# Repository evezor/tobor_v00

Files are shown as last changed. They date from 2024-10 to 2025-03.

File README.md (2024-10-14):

# tobor_v00
Tobor (robot spelled backwards), was built to be the most versatile open-source robotics system

Find out more about this project, additional source files will be released [here](https://www.crowdsupply.com/evezor-inc/tobor-robotics-and-automation-platform)

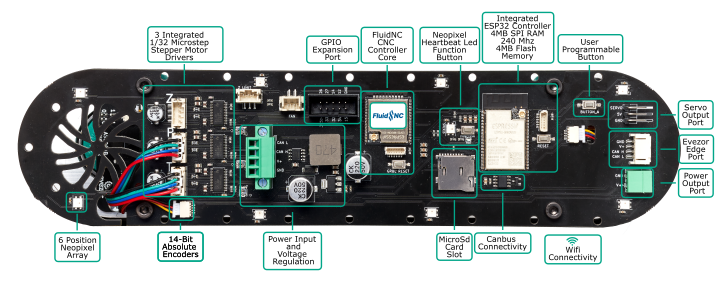
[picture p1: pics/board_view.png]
board_view

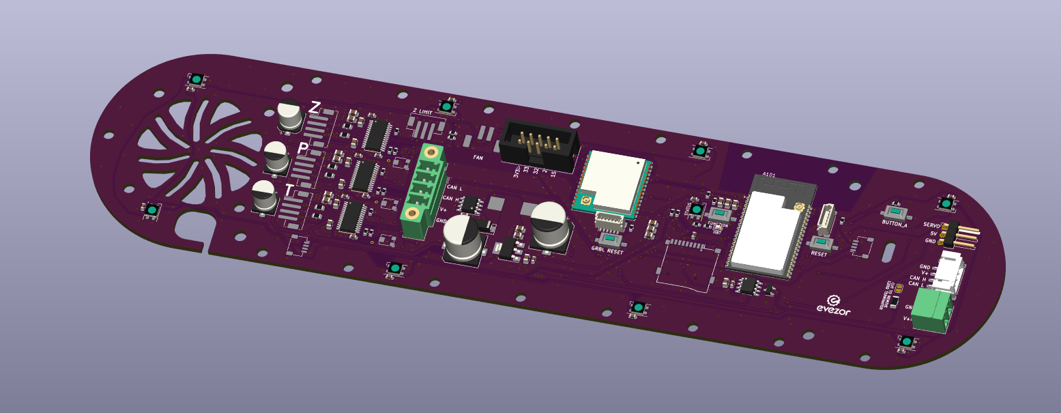
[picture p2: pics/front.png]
front_view

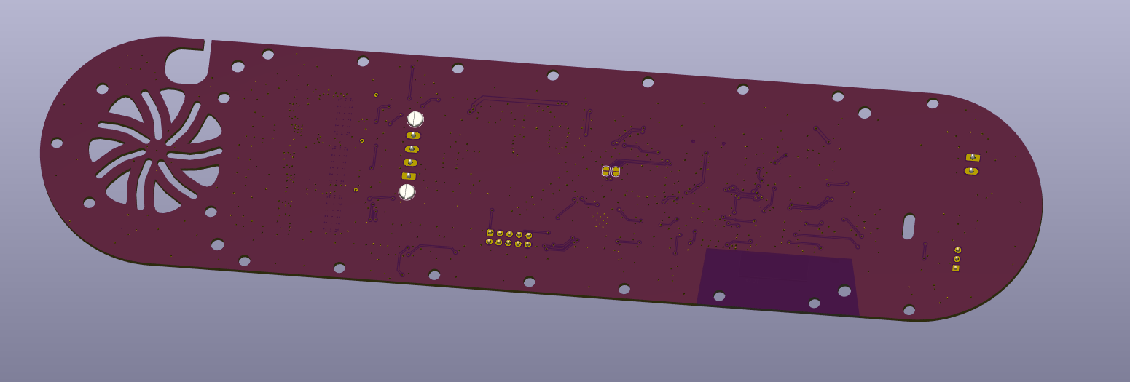
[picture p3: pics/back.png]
back

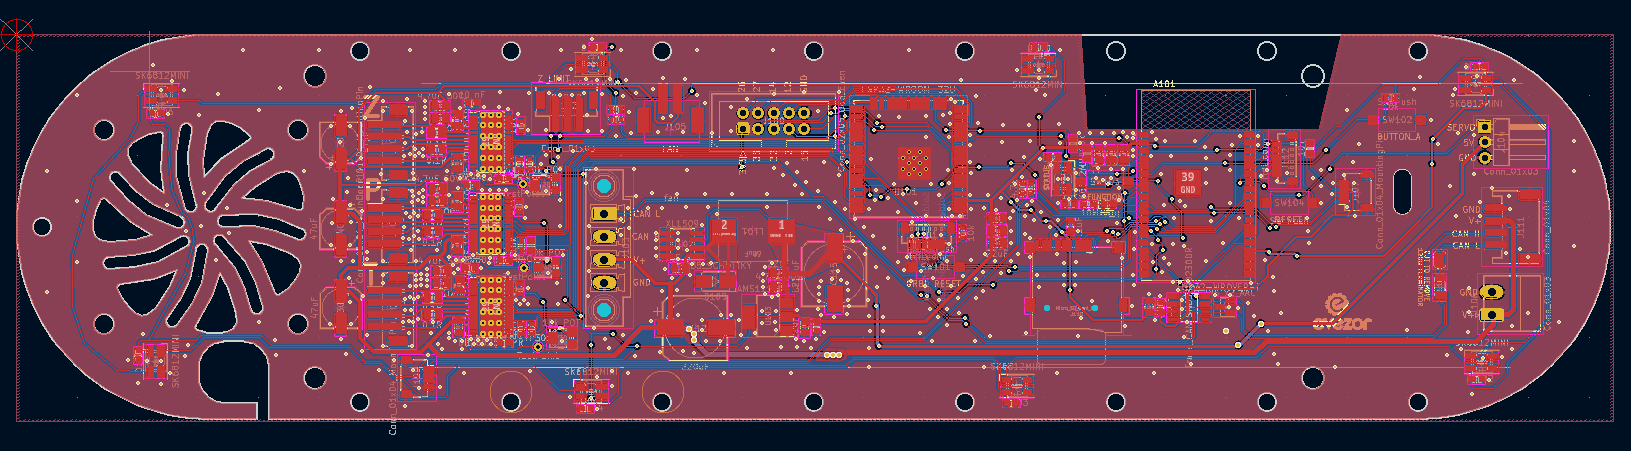
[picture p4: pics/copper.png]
copper


Tobor Robot Arm Features

* ESP32 microcontroller with 4 MB SPIRAM
    * Runs Micropython
* 3 DRV8825 stepper motor drivers
* 2 AS5048B 14-bit absolute encoders
    * Allows for low/no motion homing
    * Collaborative programming
* 8 position addressable LED ring
    * Can be used to display states of motors or the machine
* External stepper driver and peripheral port
* CNC controller powered by Fluid NC with dedicated FTDI and reset switch
* Micro-SD card slot
* WiFi enabled
* CANbus Edge Board Interface
* Servo header
* 24 VDC power input
* 1 user programmable tactile button
* Reset button
* FTDI port
* Edgeboard standards
    * Heartbeat LED
    * Function button
    * Status addressable LED

Find out more about this project, additional source files will be released [here](https://www.crowdsupply.com/evezor-inc/tobor-robotics-and-automation-platform)

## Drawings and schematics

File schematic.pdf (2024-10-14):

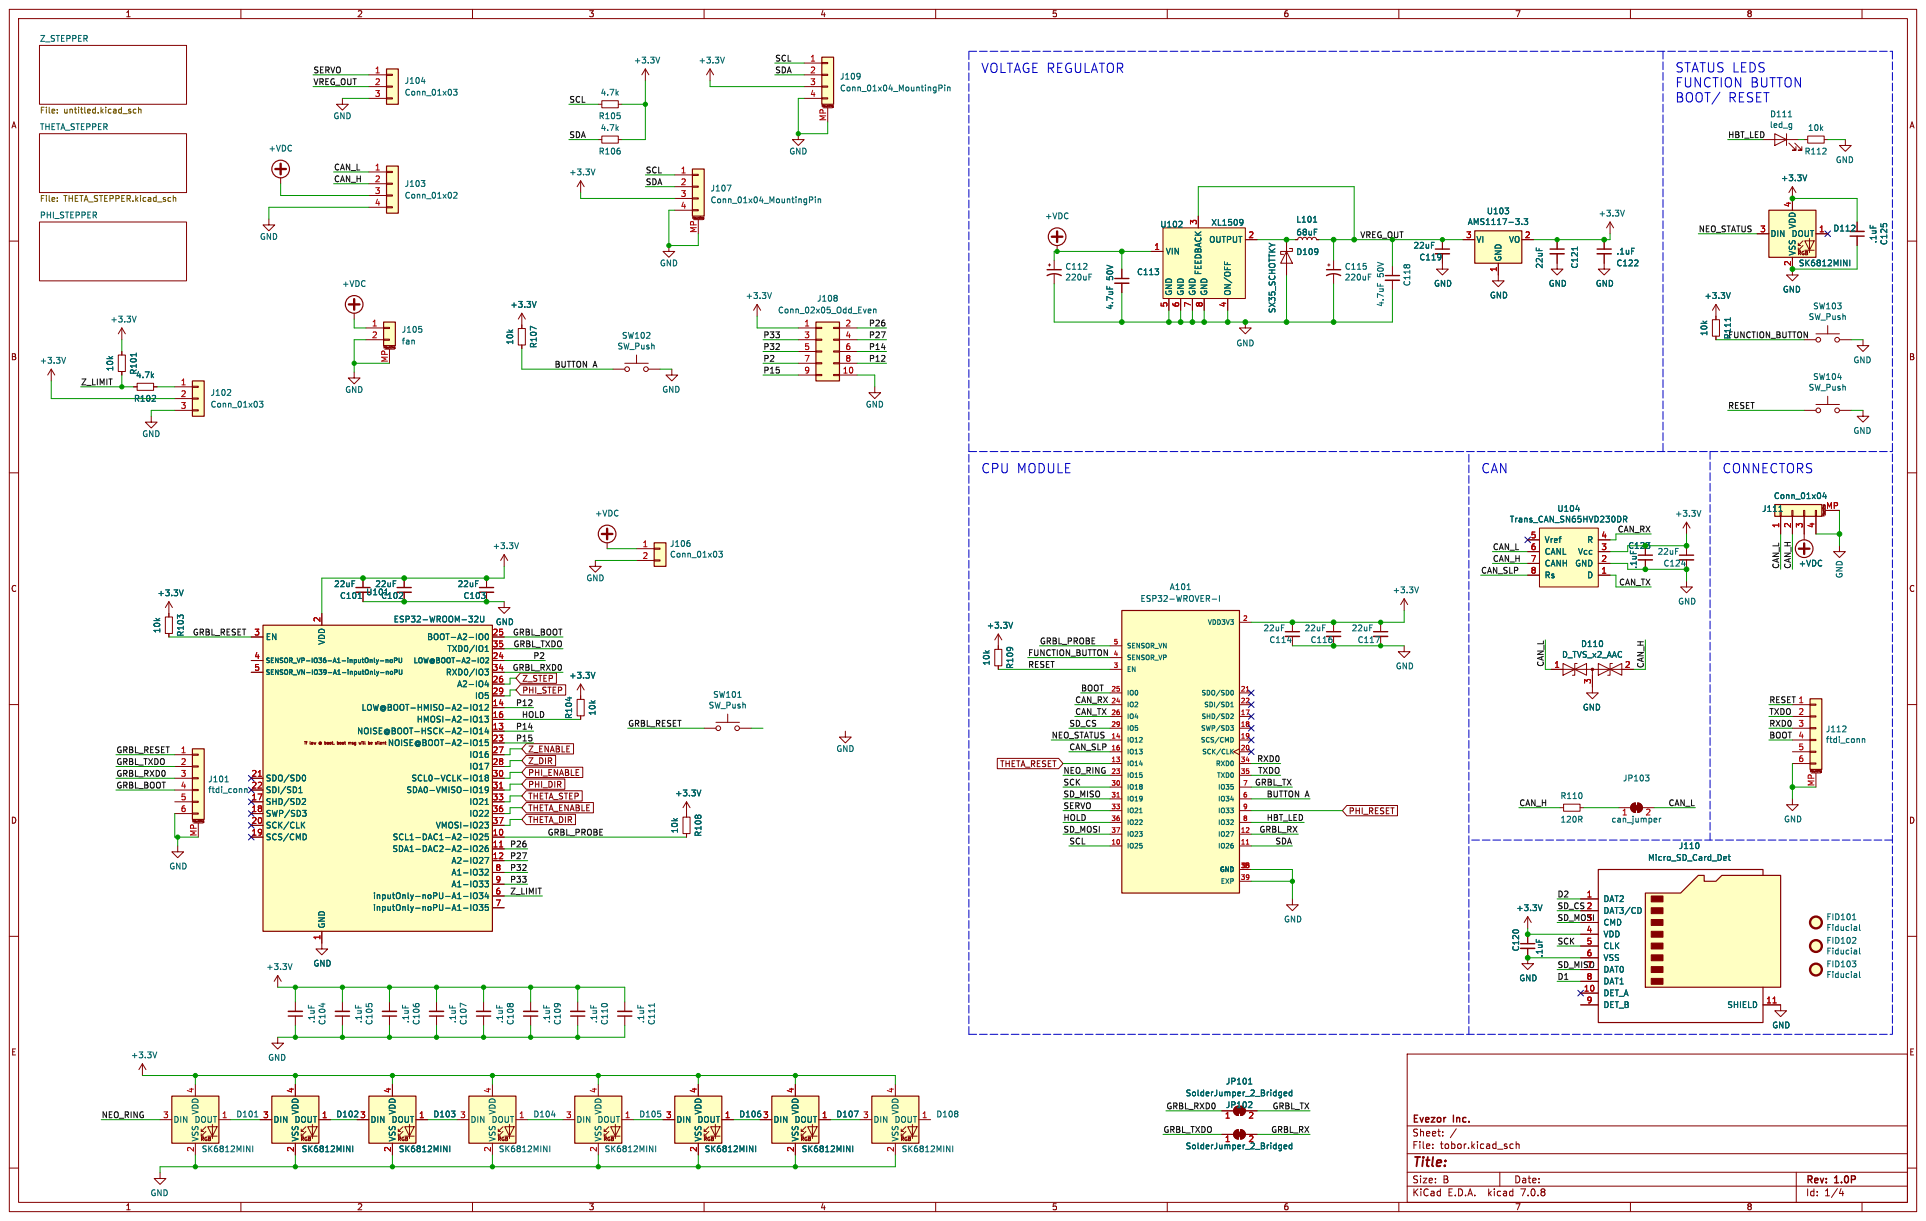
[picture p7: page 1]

2 SCK/CLK 20 SDO/SD0 21 SDI/SD1 22 NOISE@BOOT-A2-IO15 23

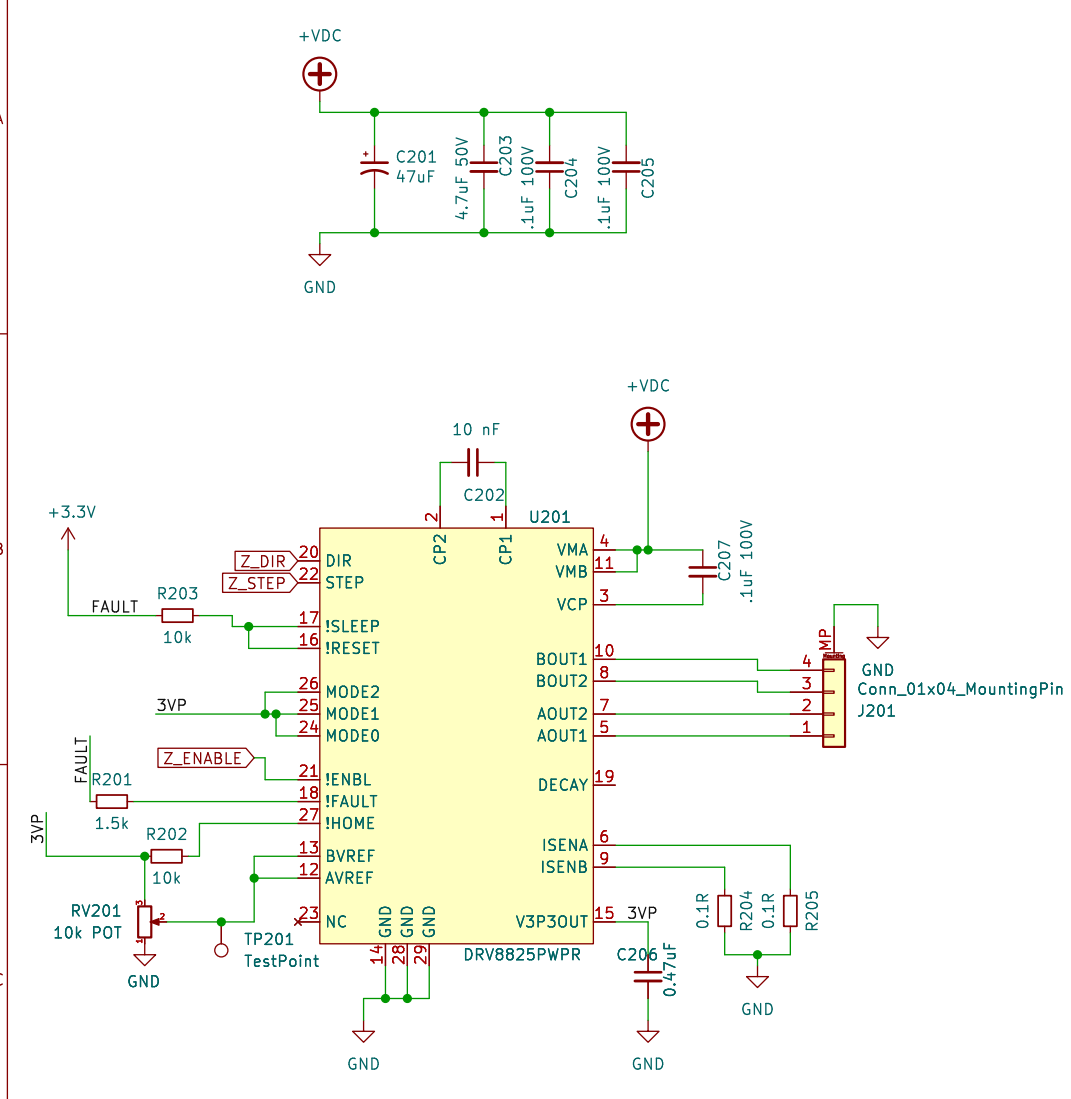
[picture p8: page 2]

1 BOUT1 10 VMB 11 AVREF 12 BVREF 13 GND 14 V3P3OUT 15

Id: 2/4 Title: File: untitled.kicad_sch Sheet: /Z_STEPPER/

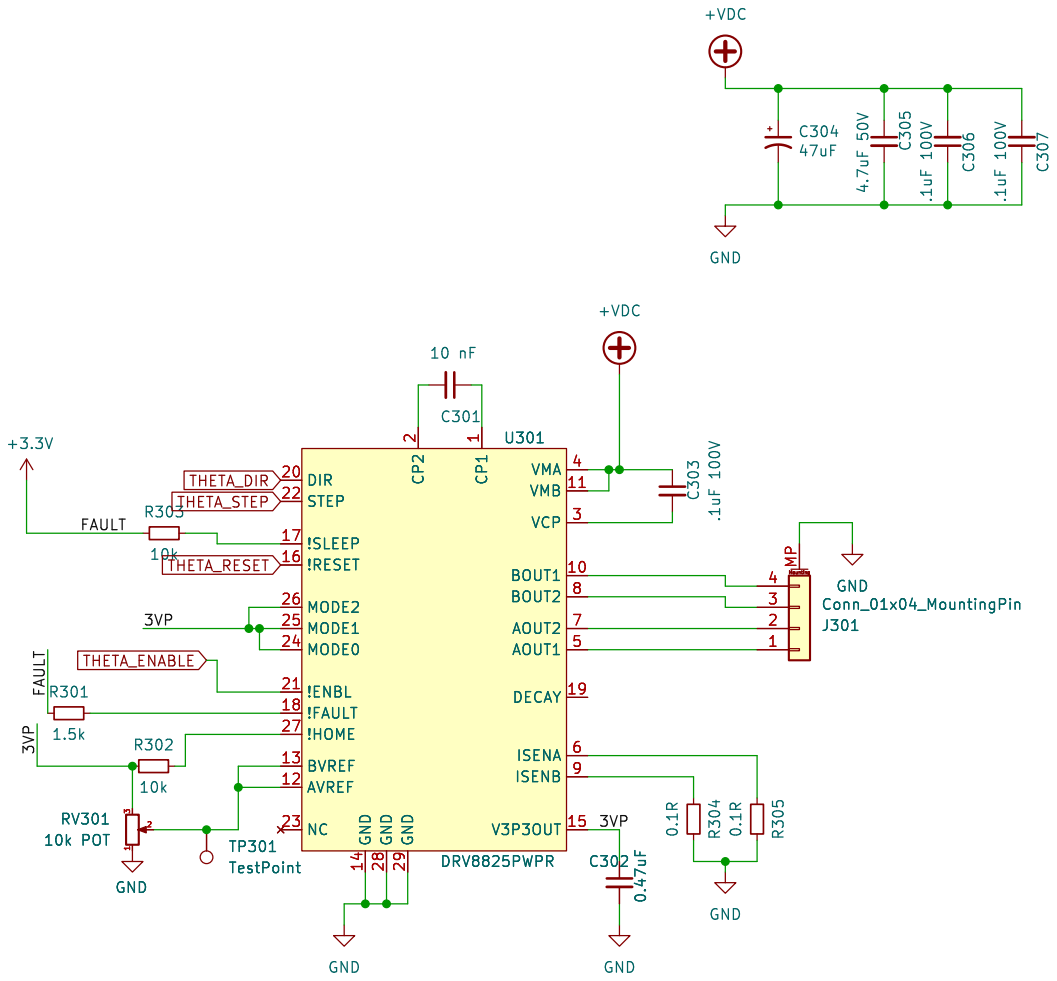
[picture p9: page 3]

Id: 3/4 Title: File: THETA_STEPPER.kicad_sch Sheet: /THETA_STEPPER/ C303 .1uF 100V+3.3V R301

1 BOUT1 10 VMB 11 AVREF 12 BVREF 13 GND 14 V3P3OUT 15

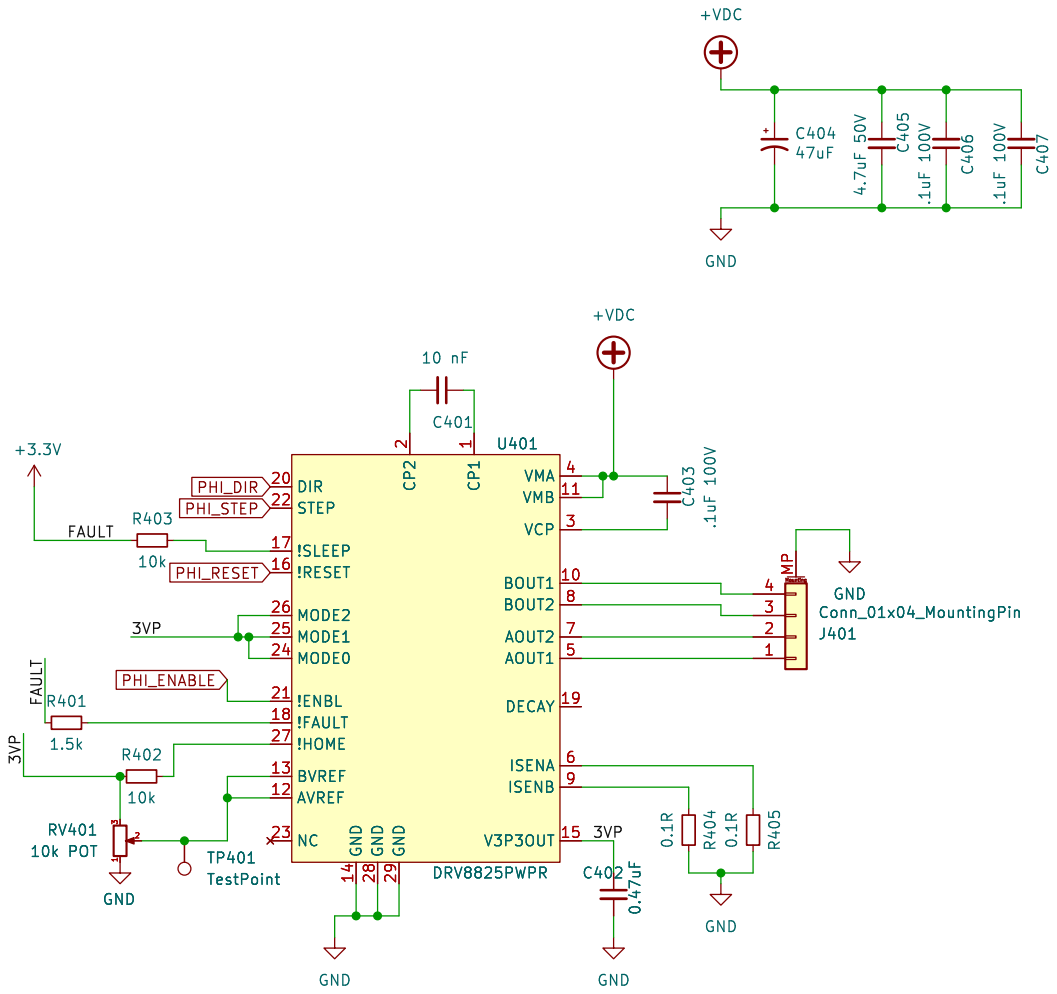
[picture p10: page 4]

4 MP C402 0.47uF U401 DRV8825PWPR CP1
Id: 4/4 Title: File: PHI_STEPPER.kicad_sch Sheet: /PHI_STEPPER/ CP1

1 BOUT1 10 VMB 11 AVREF 12 BVREF 13 GND 14 V3P3OUT 15

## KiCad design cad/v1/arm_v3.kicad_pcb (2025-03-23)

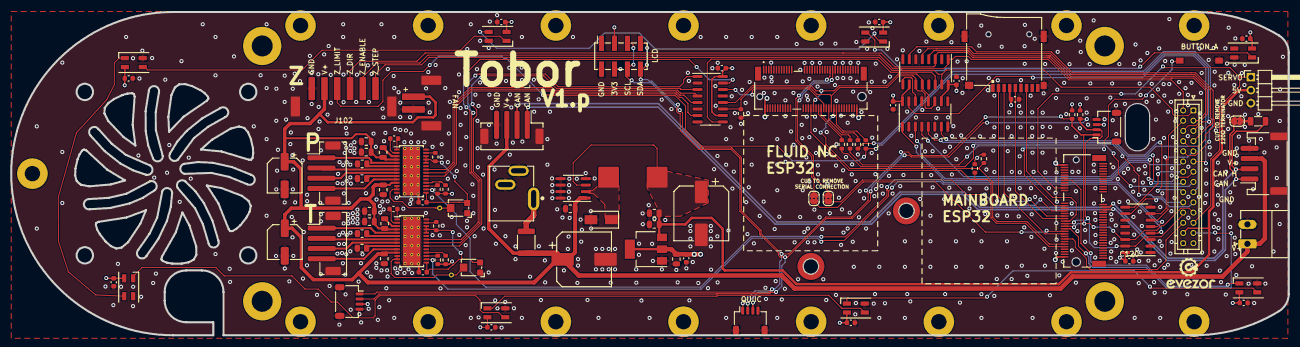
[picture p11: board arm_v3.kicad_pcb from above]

Board: 4 copper layers, 250.2 x 63.3 mm, 121 parts (0 on the bottom side), 98 nets.

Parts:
C101, C102, C103, C104, C105, C106, C107, C108, C114, C116, C117, C118, C119, C120: .1uF; C_0603_1608Metric
C109, C111: 220uF; CP_Elec_10x10.5
C110, C112, C205, C305: 4.7uF 50V; C_0805_2012Metric
C113, C115: 22uF; C_0805_2012Metric
C201, C301: 10 nF; C_0603_1608Metric
C202, C302: 0.47uF; C_0603_1608Metric
C203, C206, C207, C303, C306, C307: .1uF 100V; C_0805_2012Metric
C204, C304: 47uF; CP_Elec_6.3x7.7
D101, D102, D103, D104, D105, D106, D107, D108: SK6812MINI; LED_SK6812MINI_PLCC4_3.5x3.5mm_P1.75mm
D109: SX35_SCHOTTKY; D_SMA
F101: Polyfuse_Small; Fuse_1812_4532Metric
H101, H102, H103, H104: MountingHole; MountingHole_4.1mm_M4_DIN965_Pad
H105, H106, H107, H108, H109, H110, H111, H112, H113, H114, H115, H116, H117, H118, H119, H120, H121: MountingHole; MountingHole_3mm_Pad
H122, H123: MountingHole; Mounting_Wuerth_WA-SMSI-M2_H2.5mm_9774025243
J101: Conn_01x03; PhoenixContact_MC_1,5_2-G-3.81_1x02_P3.81mm_Horizontal
J102: Conn_01x06_MountingPin; CONN_JST_XH_6_VERTICAL
J103: fan; JST_XH_2_VERTICAL
J104: Conn_01x03; PinHeader_1x03_P2.54mm_Horizontal
J105: Conn_02x04_Odd_Even; PinSocket_2x04_P2.54mm_Vertical_SMD
J106, J108, J110: Conn_01x04_MountingPin; JST_SH_SM04B-SRSS-TB_1x04-1MP_P1.00mm_Horizontal
J107: Barrel_Jack_Switch; Vertical_barrel
J109: Conn_02x10_Odd_Even; JST_PHD_B28B-PHDSS_2x14_P2.00mm_Vertical
J111: Micro_SD_Card_Det; Conn_uSDcard
J112: Conn_01x04; JST_PH_S4B-PH-SM4-TB_1x04-1MP_P2.00mm_Horizontal
J113: Conn_01x02; JST_PH_B4B-PH-SM4-TB_1x04-1MP_P2.00mm_Vertical
J114, J115: Bus_M.2_Socket_E_ESP32; AMPHENOL_MDT420E02002
J201, J301: Conn_01x04_MountingPin; JST_PH_B4B-PH-SM4-TB_1x04-1MP_P2.00mm_Vertical
JP101, JP102: SolderJumper_2_Bridged; SolderJumper-2_P1.3mm_Bridged2Bar_RoundedPad1.0x1.5mm
JP103: can_jumper; SolderJumper-2_P1.3mm_Bridged2Bar_RoundedPad1.0x1.5mm
L101: 68uF; INDUCTOR-68uH
R101, R102: 4.7k; R_0603_1608Metric
R103: 120R; R_1206_3216Metric
R104, R105, R106, R202, R203, R302, R303: 10k; R_0603_1608Metric
R107, R108, R109, R110: 220R; R_0603_1608Metric
R201, R301: 1.5k; R_0603_1608Metric
R204, R205, R304, R305: 0.1R; R_0805_2012Metric
RV201, RV301: 10k POT; Potentiometer_Bourns_TC33X_Vertical
SW101: SW_Push; SWITCH_2x3_SMD_TACTILE_GREEN
TP201, TP301: TestPoint; TestPoint_THTPad_D1.0mm_Drill0.5mm
U101: XL1509; SOIC-8_3.9x4.9mm_P1.27mm
U102: AMS1117-3.3; SOT-223-3_TabPin2
U103, U104, U105: 74AHCT595; SOIC-16_3.9x9.9mm_P1.27mm
U106: PCF8574; SOIC-16_3.9x9.9mm_P1.27mm
U201, U301: DRV8825PWPR; HTSSOP-28-1EP_4.4x9.7mm_P0.65mm_EP3.4x9.5mm_ThermalVias

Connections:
+3V3: C101.2, C102.2, C103.2, C104.2, C105.2, C106.2, C107.2, C108.2, C114.1, C115.1, C116.1, C117.2, C118.2, C119.2, C120.1, D101.4 (VDD), D102.4 (VDD), D103.4 (VDD), D104.4 (VDD), D105.4 (VDD), D106.4 (VDD), D107.4 (VDD), D108.4 (VDD), J105.3, J105.4, J106.3, J108.3, J109.27, J110.3, J111.4 (VDD), J114.2 (3.3V), J114.74 (3.3V), J115.2 (3.3V), J115.74 (3.3V), R101.1, R102.1, R104.2, R106.2, R201.2, R203.2, R301.2, R303.2, U102.2 (VO), U103.10 (~SRCLR), U103.16 (VCC), U104.10 (~SRCLR), U104.16 (VCC), U105.10 (~SRCLR), U105.16 (VCC), U106.16 (VDD)
+5V: C111.1, C112.1, C113.1, J104.2, J109.26, L101.1, U101.3 (FEEDBACK), U102.3 (VI)
+VDC: C109.1, C110.1, C203.1, C204.1, C205.1, C206.2, C207.2, C303.1, C304.1, C305.1, C306.2, C307.2, F101.1, J101.1, J102.5, J103.1, J112.3, J113.3, U101.1 (VIN), U201.4 (VMA), U201.11 (VMB), U301.4 (VMA), U301.11 (VMB)
/A_DIR: J109.8, U104.7 (QH)
/A_ENABLE: J109.7, U104.5 (QF)
/A_LIMIT: J109.10, R108.1
/A_RESET: J109.9, U106.7 (P3)
/A_STEP: J109.6, U104.4 (QE)
/BUTTON A: J114.34, SW101.1
/B_DIR: J109.13, U105.3 (QD)
/B_ENABLE: J109.12, U105.1 (QB)
/B_LIMIT: J109.15, R109.1
/B_RESET: J109.14, U106.9 (P4)
/B_STEP: J109.11, U105.15 (QA)
/CAN_H: J112.2, J113.2, J114.35 (CAN_H), R103.2
/CAN_L: J112.1, J113.1, J114.37 (CAN_L), JP103.2 (B)
/C_DIR: J109.18, U105.7 (QH)
/C_ENABLE: J109.17, U105.5 (QF)
/C_LIMIT: J109.20, R110.1
/C_RESET: J109.19, U106.10 (P5)
/C_STEP: J109.16, U105.4 (QE)
/GRBL_PROBE: J114.66, J115.38, R104.1
/GRBL_RX: J114.38, JP102.2 (B)
/GRBL_RXD0: J115.53 (UART_RX), JP101.1 (A)
/GRBL_TX: J114.54, JP101.2 (B)
/GRBL_TXDO: J115.55 (UART_TX), JP102.1 (A)
/HOLD: J114.64, J115.56, R106.1
/I2S_CLK: J115.54, R105.2, U103.11 (SRCLK), U104.11 (SRCLK), U105.11 (SRCLK)
/I2S_DATA: J115.48, U103.14 (SER)
/I2S_WS: J115.40, U103.12 (RCLK), U104.12 (RCLK), U105.12 (RCLK)
/NEO_RING: D101.3 (DIN), J114.14
/P25: J109.25, J114.52
/P60: J109.24, J114.60
/PHI_STEPPER/3VP: C302.1, R302.2, RV301.3, U301.15 (V3P3OUT), U301.24 (MODE0), U301.25 (MODE1), U301.26 (MODE2)
/SCK: J111.5 (CLK), J114.44
/SCL: J105.5, J105.6, J106.1, J108.1, J109.21, J110.1, J114.50, R101.2, U106.14 (SCL)
/SDA: J105.7, J105.8, J106.2, J108.2, J109.22, J110.2, J114.48, R102.2, U106.15 (SDA)
/SD_CS: J111.2 (DAT3/CD), J114.42
/SD_MISO: J111.7 (DAT0), J114.46
/SD_MOSI: J111.3 (CMD), J114.56
/SERVO: J104.1, J109.23, J114.20
/THETA_STEPPER/3VP: C202.1, R202.2, RV201.3, U201.15 (V3P3OUT), U201.24 (MODE0), U201.25 (MODE1), U201.26 (MODE2)
/Z_DIR: J102.3, J109.3, U104.3 (QD)
/Z_ENABLE: J102.2, J109.2, U104.1 (QB)
/Z_LIMIT: J102.4, J109.5, R107.1
/Z_RESET: J109.4, U106.6 (P2)
/Z_STEP: J102.1, J109.1, U104.15 (QA)
GND: C101.1, C102.1, C103.1, C104.1, C105.1, C106.1, C107.1, C108.1, C109.2, C110.2, C111.2, C112.2, C113.2, C114.2, C115.2, C116.2, C117.1, C118.1, C119.1, C120.2, C202.2, C204.2, C205.2, C206.1, C207.1, C302.2, C304.2, C305.2, C306.1, C307.1, D101.2 (VSS), D102.2 (VSS), D103.2 (VSS), D105.2 (VSS), D106.2 (VSS), D107.2 (VSS), D108.2 (VSS), D109.2 (A), J101.2, J102.6, J102.MP (MountPin), J103.2, J103.MP (MountPin), J104.3, J105.1, J105.2, J106.4, J106.MP (MountPin), J107.2, J107.3, J108.4, J108.MP (MountPin), J109.28, J110.4, J110.MP (MountPin), J111.6 (VSS), J111.11 (SHIELD), J112.4, J112.MP (MountPin), J113.4, J113.MP (MountPin), J114.1 (GND), J114.7 (GND), J114.18 (GND), J114.33 (GND), J114.36 (GND), J114.39 (GND), J114.45 (GND), J114.57 (GND), J114.63 (GND), J114.69 (GND), J114.75 (GND), J115.1 (GND), J115.7 (GND), J115.18 (GND), J115.33 (GND), J115.36 (GND), J115.39 (GND), J115.45 (GND), J115.57 (GND), J115.63 (GND), J115.69 (GND), J115.75 (GND), J201.MP (MountPin), J301.MP (MountPin), R105.1, R204.1, R205.1, R304.1, R305.1, RV201.1, RV301.1, SW101.2, U101.4 (ON/OFF), U101.5 (GND), U101.6 (GND), U101.7 (GND), U101.8 (GND), U102.1 (GND), U103.8 (GND), U103.13 (~OE), U104.8 (GND), U104.13 (~OE), U105.8 (GND), U105.13 (~OE), U106.1 (A0), U106.2 (A1), U106.3 (A2), U106.8 (VSS), U201.14 (GND), U201.28 (GND), U201.29 (GND), U301.14 (GND), U301.28 (GND), U301.29 (GND)
unnamed: D101.1 (DOUT), D102.3 (DIN)
unnamed: D102.1 (DOUT), D103.3 (DIN)
unnamed: D103.1 (DOUT), D104.3 (DIN)
unnamed: D104.1 (DOUT), D105.3 (DIN)
unnamed: D105.1 (DOUT), D106.3 (DIN)
unnamed: D106.1 (DOUT), D107.3 (DIN)
unnamed: D107.1 (DOUT), D108.3 (DIN)
unnamed: D109.1 (K), L101.2, U101.2 (OUTPUT)
unnamed: F101.2, J107.1
unnamed: J115.44, R110.2
unnamed: J115.46, R109.2
unnamed: J115.52, R108.2
unnamed: J115.58, R107.2
unnamed: J201.1, U201.5 (AOUT1)
unnamed: J201.2, U201.7 (AOUT2)
unnamed: J201.3, U201.8 (BOUT2)
unnamed: J201.4, U201.10 (BOUT1)
unnamed: J301.1, U301.5 (AOUT1)
unnamed: J301.2, U301.7 (AOUT2)
unnamed: J301.3, U301.8 (BOUT2)
unnamed: J301.4, U301.10 (BOUT1)
unnamed: JP103.1 (A), R103.1
unnamed: U103.9 (QH'), U104.14 (SER)
unnamed: U104.9 (QH'), U105.14 (SER)
unnamed: R201.1, U201.18 (!FAULT)
unnamed: R202.1, U201.27 (!HOME)
unnamed: R203.1, U201.17 (!SLEEP)
unnamed: RV201.2, TP201.1, U201.12 (AVREF), U201.13 (BVREF)
unnamed: C201.1, U201.1 (CP1)
unnamed: C201.2, U201.2 (CP2)
unnamed: R205.2, U201.6 (ISENA)
unnamed: R204.2, U201.9 (ISENB)
unnamed: C203.2, U201.3 (VCP)
unnamed: R301.1, U301.18 (!FAULT)
unnamed: R302.1, U301.27 (!HOME)
unnamed: R303.1, U301.17 (!SLEEP)
unnamed: RV301.2, TP301.1, U301.12 (AVREF), U301.13 (BVREF)
unnamed: C301.1, U301.1 (CP1)
unnamed: C301.2, U301.2 (CP2)
unnamed: R305.2, U301.6 (ISENA)
unnamed: R304.2, U301.9 (ISENB)
unnamed: C303.2, U301.3 (VCP)
PHI_DIR: U103.7 (QH), U301.20 (DIR)
PHI_ENABLE: U103.5 (QF), U301.21 (!ENBL)
PHI_RESET: U106.5 (P1), U301.16 (!RESET)
PHI_STEP: U103.4 (QE), U301.22 (STEP)
THETA_DIR: U103.3 (QD), U201.20 (DIR)
THETA_ENABLE: U103.1 (QB), U201.21 (!ENBL)
THETA_RESET: U106.4 (P0), U201.16 (!RESET)
THETA_STEP: U103.15 (QA), U201.22 (STEP)

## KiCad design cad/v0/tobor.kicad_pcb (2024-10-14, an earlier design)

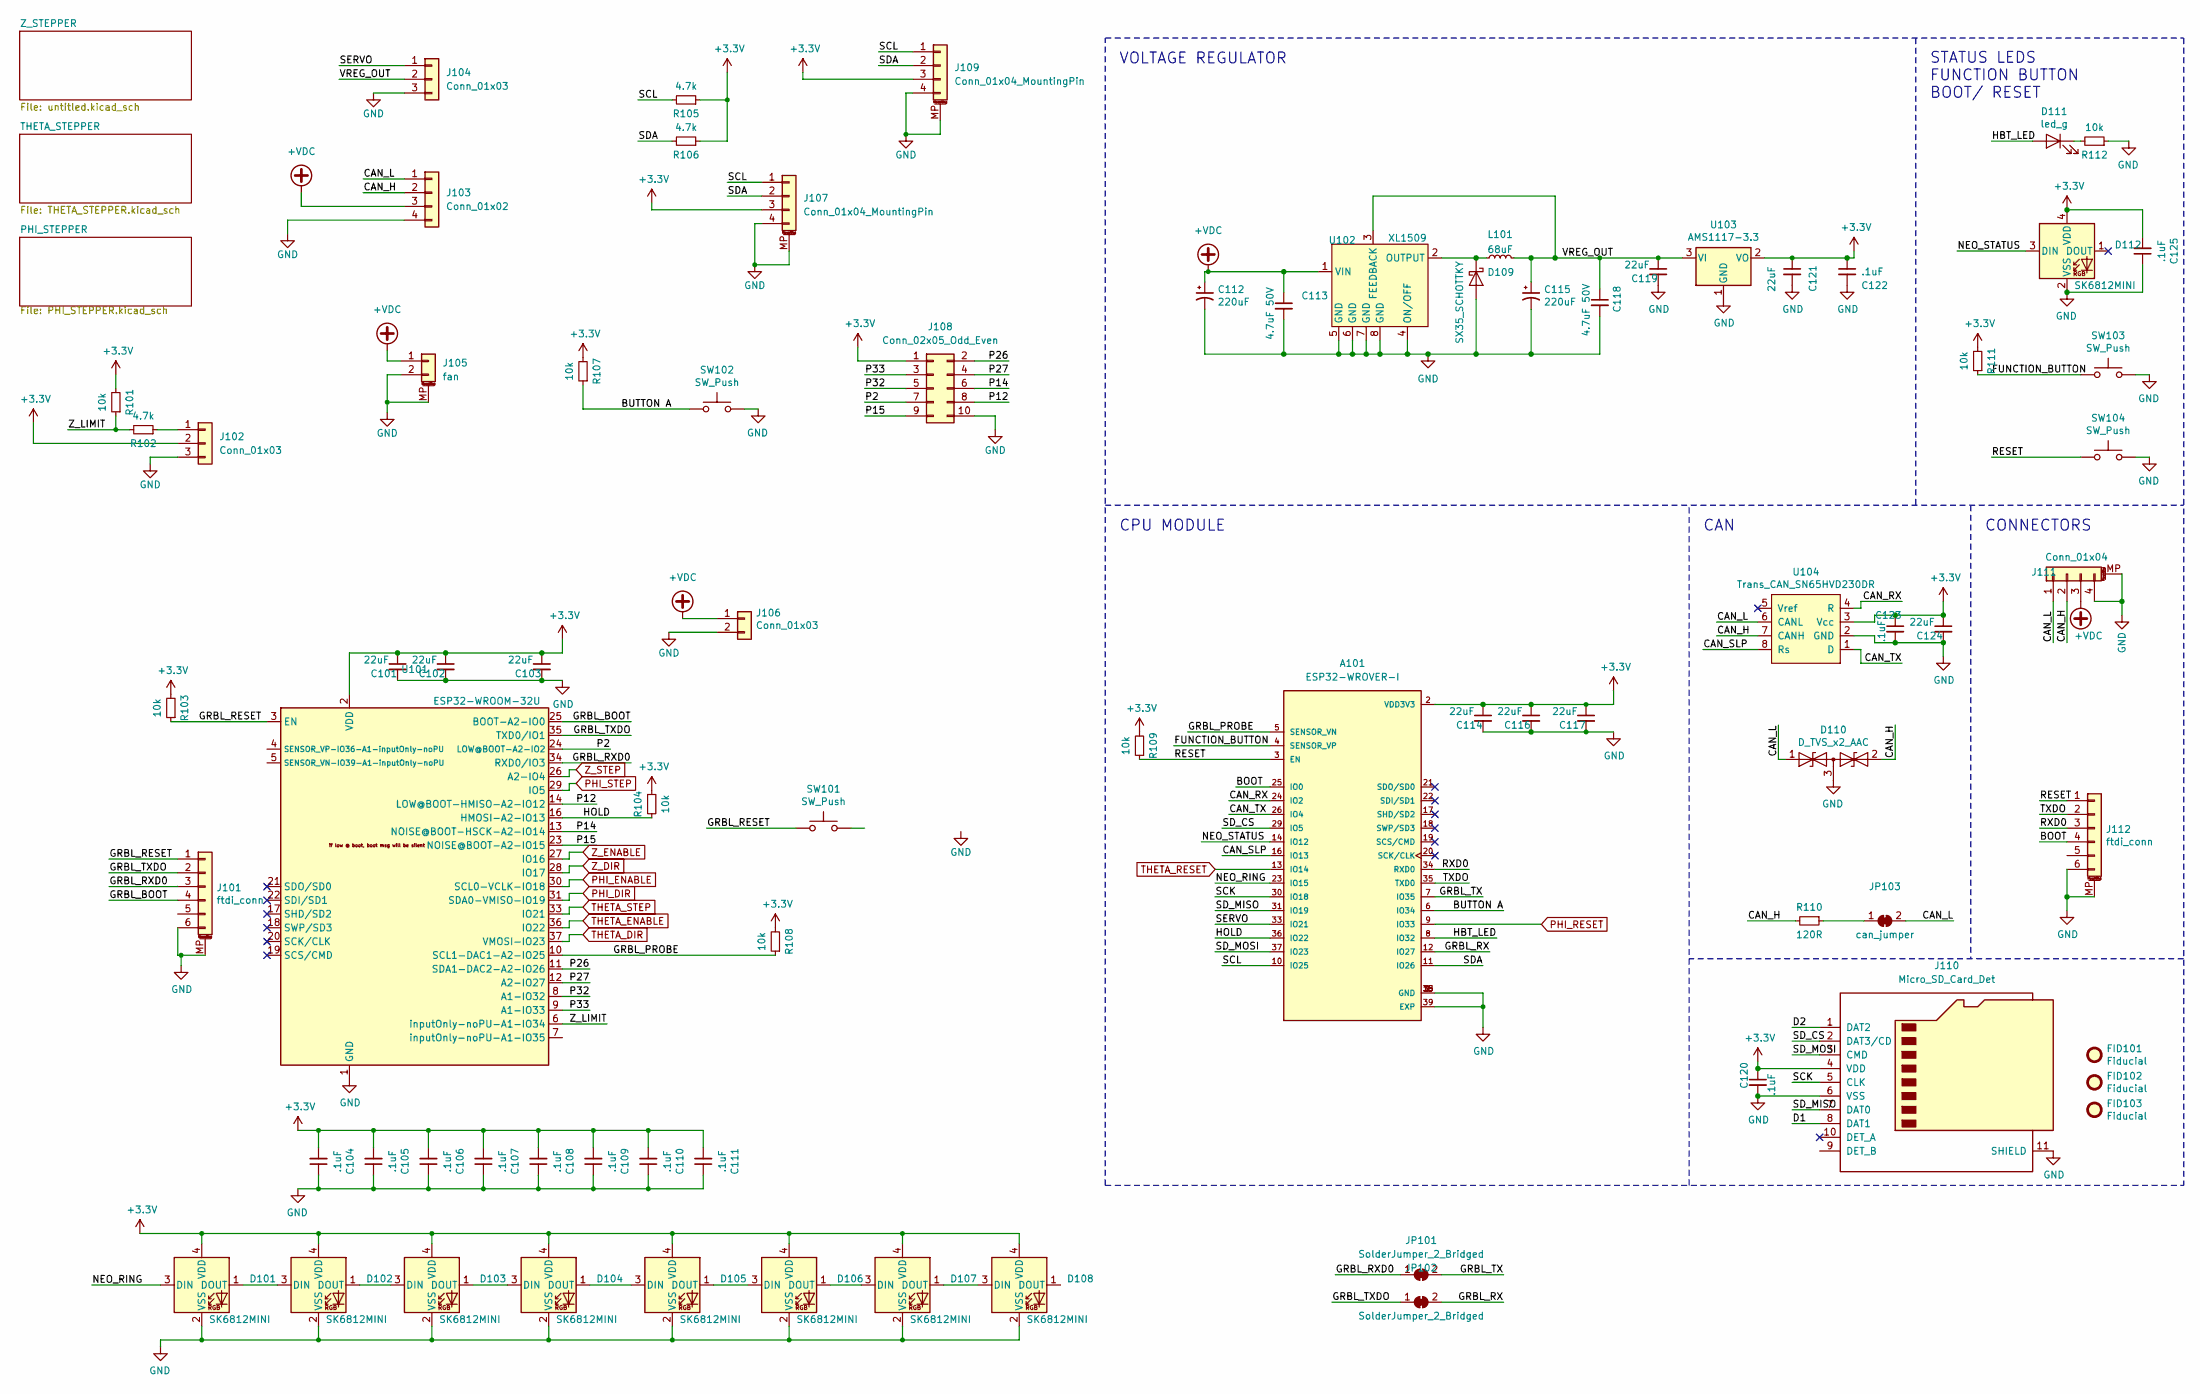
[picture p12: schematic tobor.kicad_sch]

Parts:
A101: ESP32-WROVER-I; XCVR_ESP32-WROVER-I; DIGI-KEY_PART_NUMBER 1904-1008-1-ND
C101, C102, C103, C114, C116, C117, C119, C121, C124: 22uF; C_0805_2012Metric
C104, C105, C106, C107, C108, C109, C110, C111, C120, C122, C123, C125: .1uF; C_0603_1608Metric
C112, C115: 220uF; CP_Elec_10x10.5
C113, C118: 4.7uF 50V; C_0805_2012Metric
D101, D102, D103, D104, D105, D106, D107, D108, D112: SK6812MINI; LED_SK6812MINI_PLCC4_3.5x3.5mm_P1.75mm
D109: SX35_SCHOTTKY; D_SMA
D110: D_TVS_x2_AAC; SOT-23
D111: led_g; LED_0603_1608Metric
FID101, FID102, FID103: Fiducial; Fiducial_0.5mm_Mask1mm
J101, J112: ftdi_conn; JST_SH_BM06B-SRSS-TB_1x06-1MP_P1.00mm_Vertical
J102: Conn_01x03; JST_PH_B3B-PH-SM4-TB_1x03-1MP_P2.00mm_Vertical
J103: Conn_01x02; PhoenixContact_MCV_1,5_4-GF-3.81_1x04_P3.81mm_Vertical_Thre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
J104: Conn_01x03; PinHeader_1x03_P2.54mm_Horizontal
J105: fan; JST_XH_2_VERTICAL
J106: Conn_01x03; PhoenixContact_MC_1,5_2-G-3.81_1x02_P3.81mm_Horizontal
J107, J109: Conn_01x04_MountingPin; JST_SH_SM04B-SRSS-TB_1x04-1MP_P1.00mm_Horizontal
J108: Conn_02x05_Odd_Even; IDC-Header_2x05_P2.54mm_Vertical
J110: Micro_SD_Card_Det; Conn_uSDcard
J111: Conn_01x04; JST_PH_S4B-PH-SM4-TB_1x04-1MP_P2.00mm_Horizontal
JP101, JP102: SolderJumper_2_Bridged; SolderJumper-2_P1.3mm_Bridged2Bar_RoundedPad1.0x1.5mm
JP103: can_jumper; SolderJumper-2_P1.3mm_Bridged2Bar_RoundedPad1.0x1.5mm
L101: 68uF; INDUCTOR-68uH
R101, R103, R104, R107, R108, R109, R111, R112: 10k; R_0603_1608Metric
R102, R105, R106: 4.7k; R_0603_1608Metric
R110: 120R; R_1206_3216Metric
SW101, SW102, SW103, SW104: SW_Push; SWITCH_2x3_SMD_TACTILE_GREEN
U101: ESP32-WROOM-32U; ESP32-WROOM-32U_evezor
U102: XL1509; SOIC-8_3.9x4.9mm_P1.27mm
U103: AMS1117-3.3; SOT-223-3_TabPin2
U104: Trans_CAN_SN65HVD230DR; CAN-TRANS-SN65HVD230DR

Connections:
+3V3: A101.2 (VDD3V3), C101.1, C102.1, C103.1, C104.2, C105.2, C106.2, C107.2, C108.2, C109.2, C110.2, C111.2, C114.1, C116.1, C117.1, C120.1, C121.1, C122.1, C123.1, C124.1, C125.2, D101.4 (VDD), D102.4 (VDD), D103.4 (VDD), D104.4 (VDD), D105.4 (VDD), D106.4 (VDD), D107.4 (VDD), D108.4 (VDD), D112.4 (VDD), J102.2, J107.3, J108.1, J109.3, J110.4 (VDD), R101.2, R103.2, R104.1, R105.1, R106.1, R107.2, R108.2, R109.2, R111.2, U101.2 (VDD), U103.2 (VO), U104.3 (Vcc); also elsewhere on the board
+VDC: C112.1, C113.1, J103.3, J105.1, J106.1, J111.3, U102.1 (VIN); also elsewhere on the board
/BOOT: A101.25 (IO0), J112.4
/BUTTON A: A101.6 (IO34), R107.1, SW102.1
/CAN_H: D110.2 (A2), J103.2, J111.2, R110.2, U104.7 (CANH)
/CAN_L: D110.1 (A1), J103.1, J111.1, JP103.2 (B), U104.6 (CANL)
/CAN_RX: A101.24 (IO2), U104.4 (R)
/CAN_SLP: A101.16 (IO13), U104.8 (Rs)
/CAN_TX: A101.26 (IO4), U104.1 (D)
/D1: J110.8 (DAT1)
/D2: J110.1 (DAT2)
/FUNCTION_BUTTON: A101.4 (SENSOR_VP), R111.1, SW103.1
/GRBL_BOOT: J101.4, U101.25 (BOOT-A2-IO0)
/GRBL_PROBE: A101.5 (SENSOR_VN), R108.1, U101.10 (SCL1-DAC1-A2-IO25)
/GRBL_RESET: J101.1, R103.1, SW101.1, U101.3 (EN)
/GRBL_RX: A101.12 (IO27), JP102.2 (B)
/GRBL_RXD0: J101.3, JP101.1 (A), U101.34 (RXD0/IO3)
/GRBL_TX: A101.7 (IO35), JP101.2 (B)
/GRBL_TXDO: J101.2, JP102.1 (A), U101.35 (TXD0/IO1)
/HBT_LED: A101.8 (IO32), D111.2 (A)
/HOLD: A101.36 (IO22), R104.2, U101.16 (HMOSI-A2-IO13)
/NEO_RING: A101.23 (IO15), D101.3 (DIN)
/NEO_STATUS: A101.14 (IO12), D112.3 (DIN)
/P2: J108.7, U101.24 (LOW@BOOT-A2-IO2)
/P12: J108.8, U101.14 (LOW@BOOT-HMISO-A2-IO12)
/P14: J108.6, U101.13 (NOISE@BOOT-HSCK-A2-IO14)
/P15: J108.9, U101.23 (NOISE@BOOT-A2-IO15)
/P26: J108.2, U101.11 (SDA1-DAC2-A2-IO26)
/P27: J108.4, U101.12 (A2-IO27)
/P32: J108.5, U101.8 (A1-IO32)
/P33: J108.3, U101.9 (A1-IO33)
/RESET: A101.3 (EN), J112.1, R109.1, SW104.1
/RXD0: A101.34 (RXD0), J112.3
/SCK: A101.30 (IO18), J110.5 (CLK)
/SCL: A101.10 (IO25), J107.1, J109.1, R105.2
/SDA: A101.11 (IO26), J107.2, J109.2, R106.2
/SD_CS: A101.29 (IO5), J110.2 (DAT3/CD)
/SD_MISO: A101.31 (IO19), J110.7 (DAT0)
/SD_MOSI: A101.37 (IO23), J110.3 (CMD)
/SERVO: A101.33 (IO21), J104.1
/TXDO: A101.35 (TXD0), J112.2
/VREG_OUT: C115.1, C118.1, C119.1, J104.2, L101.1, U102.3 (FEEDBACK), U103.3 (VI)
/Z_LIMIT: R101.1, R102.2, U101.6 (inputOnly-noPU-A1-IO34)
GND: A101.1 (GND), A101.15 (GND), A101.38 (GND), A101.39 (EXP), C101.2, C102.2, C103.2, C104.1, C105.1, C106.1, C107.1, C108.1, C109.1, C110.1, C111.1, C112.2, C113.2, C114.2, C115.2, C116.2, C117.2, C118.2, C119.2, C120.2, C121.2, C122.2, C123.2, C124.2, C125.1, D101.2 (VSS), D102.2 (VSS), D103.2 (VSS), D104.2 (VSS), D105.2 (VSS), D106.2 (VSS), D107.2 (VSS), D108.2 (VSS), D109.2 (A), D110.3 (common), D112.2 (VSS), J101.6, J101.MP (MountPin), J102.3, J103.4, J104.3, J105.2, J105.MP (MountPin), J106.2, J107.4, J107.MP (MountPin), J108.10, J109.4, J109.MP (MountPin), J110.6 (VSS), J110.11 (SHIELD), J111.4, J111.MP (MountPin), J112.6, J112.MP (MountPin), R112.1, SW101.2, SW102.2, SW103.2, SW104.2, U101.1 (GND), U101.15 (GND), U101.38 (GND), U101.39 (GND), U102.4 (ON/OFF), U102.5 (GND), U102.6 (GND), U102.7 (GND), U102.8 (GND), U103.1 (GND), U104.2 (GND); also elsewhere on the board
unnamed: D101.1 (DOUT), D102.3 (DIN)
unnamed: D102.1 (DOUT), D103.3 (DIN)
unnamed: D103.1 (DOUT), D104.3 (DIN)
unnamed: D104.1 (DOUT), D105.3 (DIN)
unnamed: D105.1 (DOUT), D106.3 (DIN)
unnamed: D106.1 (DOUT), D107.3 (DIN)
unnamed: D107.1 (DOUT), D108.3 (DIN)
unnamed: D109.1 (K), L101.2, U102.2 (OUTPUT)
unnamed: D111.1 (K), R112.2
unnamed: J102.1, R102.1
unnamed: JP103.1 (A), R110.1
PHI_DIR: U101.31 (SDA0-VMISO-IO19); also elsewhere on the board
PHI_ENABLE: U101.30 (SCL0-VCLK-IO18); also elsewhere on the board
PHI_RESET: A101.9 (IO33); also elsewhere on the board
PHI_STEP: U101.29 (IO5); also elsewhere on the board
THETA_DIR: U101.37 (VMOSI-IO23); also elsewhere on the board
THETA_ENABLE: U101.36 (IO22); also elsewhere on the board
THETA_RESET: A101.13 (IO14); also elsewhere on the board
THETA_STEP: U101.33 (IO21); also elsewhere on the board
Z_DIR: U101.28 (IO17); also elsewhere on the board
Z_ENABLE: U101.27 (IO16); also elsewhere on the board
Z_STEP: U101.26 (A2-IO4); also elsewhere on the board

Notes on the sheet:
VOLTAGE REGULATOR
CPU MODULE
CAN
STATUS LEDS FUNCTION BUTTON BOOT/ RESET
CONNECTORS

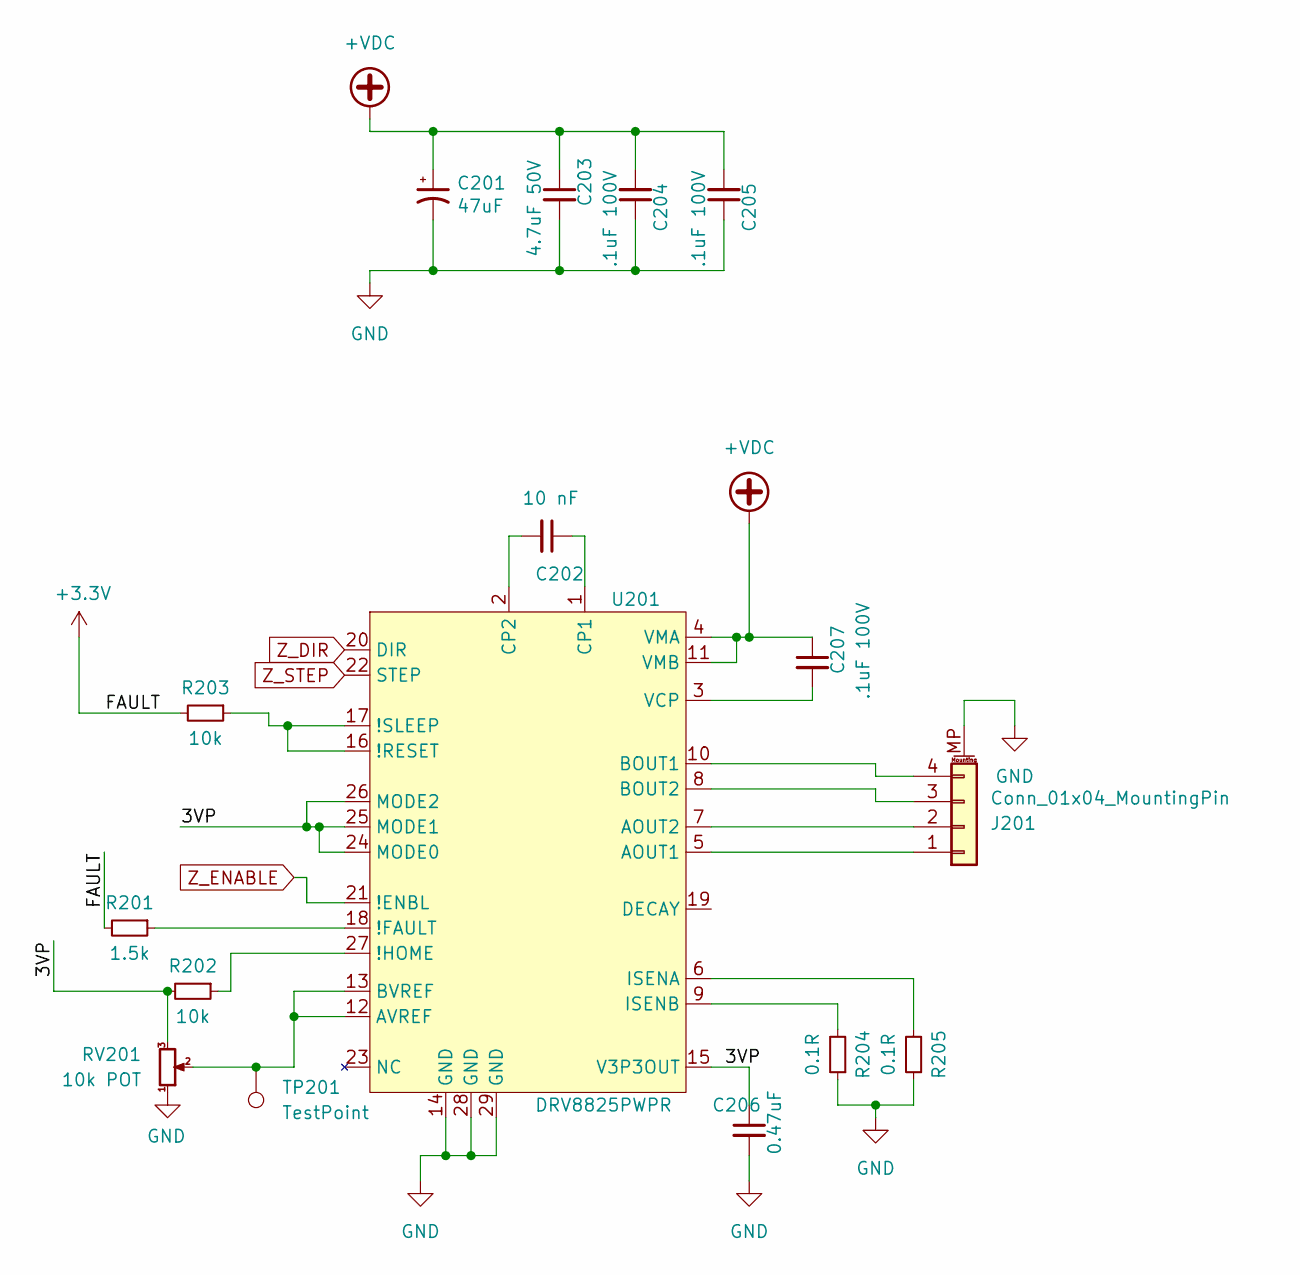
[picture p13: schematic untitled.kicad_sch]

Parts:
C201: 47uF; CP_Elec_6.3x7.7
C202: 10 nF; C_0603_1608Metric
C203: 4.7uF 50V; C_0805_2012Metric
C204, C205, C207: .1uF 100V; C_0805_2012Metric
C206: 0.47uF; C_0603_1608Metric
J201: Conn_01x04_MountingPin; JST_PH_B4B-PH-SM4-TB_1x04-1MP_P2.00mm_Vertical
R201: 1.5k; R_0603_1608Metric
R202, R203: 10k; R_0603_1608Metric
R204, R205: 0.1R; R_0805_2012Metric
RV201: 10k POT; Potentiometer_Bourns_TC33X_Vertical
TP201: TestPoint; TestPoint_THTPad_D1.0mm_Drill0.5mm
U201: DRV8825PWPR; HTSSOP-28-1EP_4.4x9.7mm_P0.65mm_EP3.4x9.5mm_ThermalVias

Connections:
+3V3: R201.2, R203.2; also elsewhere on the board
+VDC: C201.1, C203.1, C204.2, C205.2, C207.1, U201.4 (VMA), U201.11 (VMB); also elsewhere on the board
/Z_STEPPER/3VP: C206.1, R202.2, RV201.3, U201.15 (V3P3OUT), U201.24 (MODE0), U201.25 (MODE1), U201.26 (MODE2)
GND: C201.2, C203.2, C204.1, C205.1, C206.2, J201.MP (MountPin), R204.1, R205.1, RV201.1, U201.14 (GND), U201.28 (GND), U201.29 (GND); also elsewhere on the board
unnamed: J201.1, U201.5 (AOUT1)
unnamed: J201.2, U201.7 (AOUT2)
unnamed: J201.3, U201.8 (BOUT2)
unnamed: J201.4, U201.10 (BOUT1)
unnamed: R201.1, U201.18 (!FAULT)
unnamed: R202.1, U201.27 (!HOME)
unnamed: R203.1, U201.16 (!RESET), U201.17 (!SLEEP)
unnamed: RV201.2, TP201.1, U201.12 (AVREF), U201.13 (BVREF)
unnamed: C202.1, U201.1 (CP1)
unnamed: C202.2, U201.2 (CP2)
unnamed: R205.2, U201.6 (ISENA)
unnamed: R204.2, U201.9 (ISENB)
unnamed: C207.2, U201.3 (VCP)
Z_DIR: U201.20 (DIR); also elsewhere on the board
Z_ENABLE: U201.21 (!ENBL); also elsewhere on the board
Z_STEP: U201.22 (STEP); also elsewhere on the board

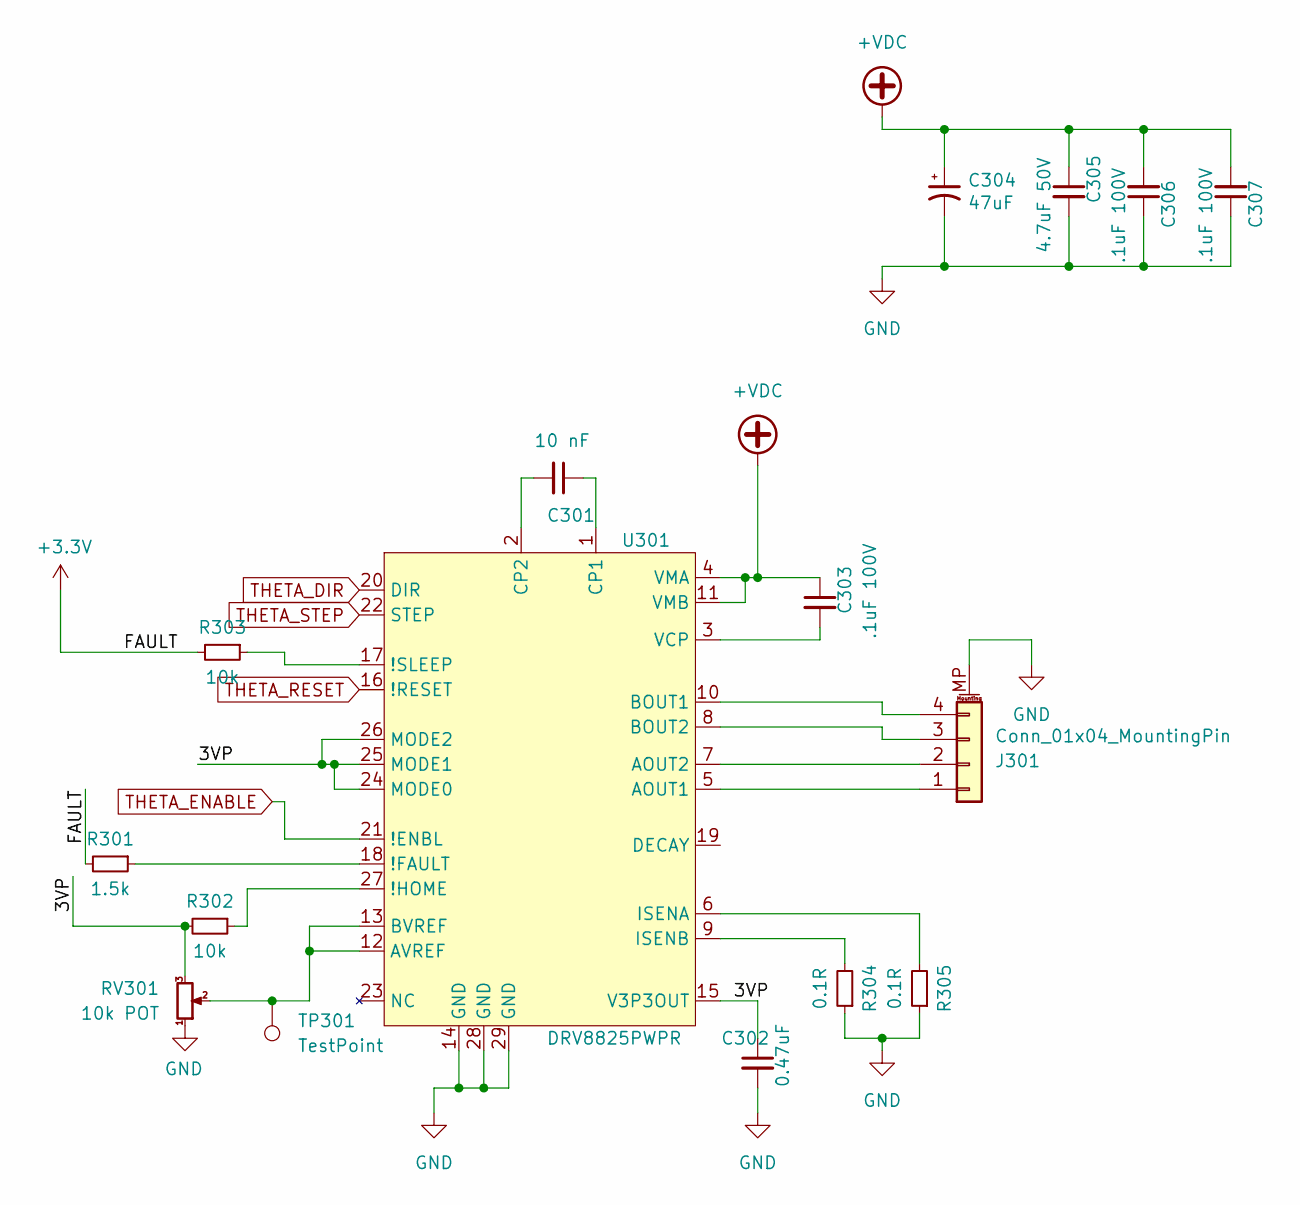
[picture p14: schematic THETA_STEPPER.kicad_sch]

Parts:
C301: 10 nF; C_0603_1608Metric
C302: 0.47uF; C_0603_1608Metric
C303, C306, C307: .1uF 100V; C_0805_2012Metric
C304: 47uF; CP_Elec_6.3x7.7
C305: 4.7uF 50V; C_0805_2012Metric
J301: Conn_01x04_MountingPin; JST_PH_B4B-PH-SM4-TB_1x04-1MP_P2.00mm_Vertical
R301: 1.5k; R_0603_1608Metric
R302, R303: 10k; R_0603_1608Metric
R304, R305: 0.1R; R_0805_2012Metric
RV301: 10k POT; Potentiometer_Bourns_TC33X_Vertical
TP301: TestPoint; TestPoint_THTPad_D1.0mm_Drill0.5mm
U301: DRV8825PWPR; HTSSOP-28-1EP_4.4x9.7mm_P0.65mm_EP3.4x9.5mm_ThermalVias

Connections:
+3V3: R301.2, R303.2; also elsewhere on the board
+VDC: C303.1, C304.1, C305.1, C306.2, C307.2, U301.4 (VMA), U301.11 (VMB); also elsewhere on the board
/THETA_STEPPER/3VP: C302.1, R302.2, RV301.3, U301.15 (V3P3OUT), U301.24 (MODE0), U301.25 (MODE1), U301.26 (MODE2)
GND: C302.2, C304.2, C305.2, C306.1, C307.1, J301.MP (MountPin), R304.1, R305.1, RV301.1, U301.14 (GND), U301.28 (GND), U301.29 (GND); also elsewhere on the board
unnamed: J301.1, U301.5 (AOUT1)
unnamed: J301.2, U301.7 (AOUT2)
unnamed: J301.3, U301.8 (BOUT2)
unnamed: J301.4, U301.10 (BOUT1)
unnamed: R301.1, U301.18 (!FAULT)
unnamed: R302.1, U301.27 (!HOME)
unnamed: R303.1, U301.17 (!SLEEP)
unnamed: RV301.2, TP301.1, U301.12 (AVREF), U301.13 (BVREF)
unnamed: C301.1, U301.1 (CP1)
unnamed: C301.2, U301.2 (CP2)
unnamed: R305.2, U301.6 (ISENA)
unnamed: R304.2, U301.9 (ISENB)
unnamed: C303.2, U301.3 (VCP)
THETA_DIR: U301.20 (DIR); also elsewhere on the board
THETA_ENABLE: U301.21 (!ENBL); also elsewhere on the board
THETA_RESET: U301.16 (!RESET); also elsewhere on the board
THETA_STEP: U301.22 (STEP); also elsewhere on the board

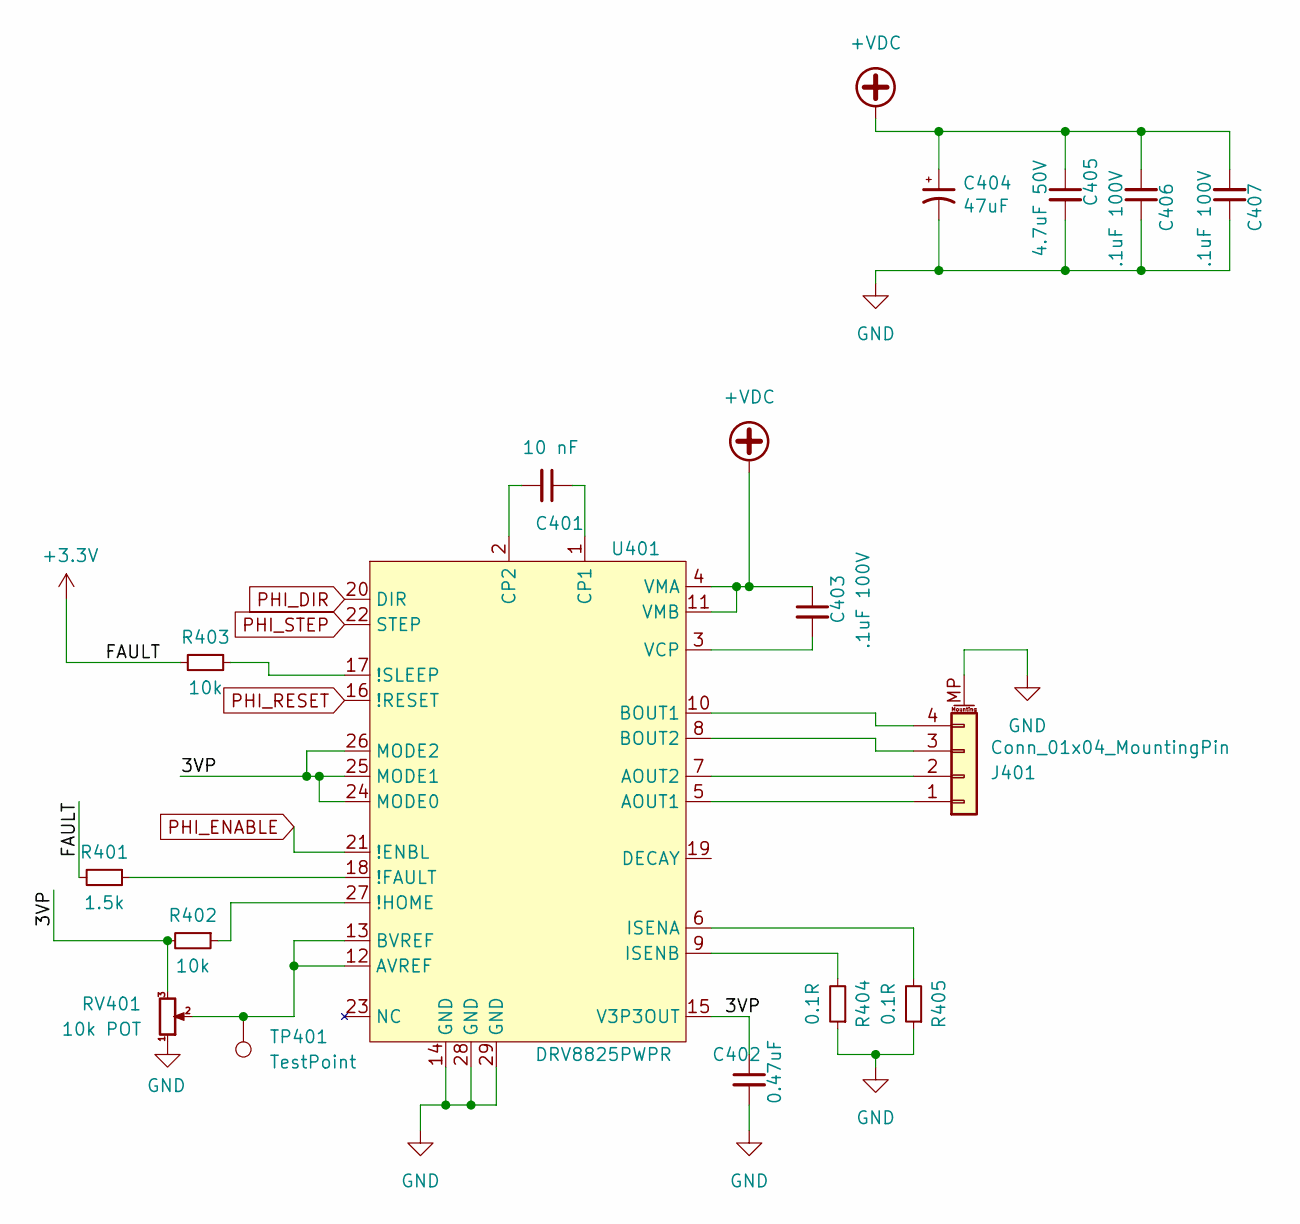
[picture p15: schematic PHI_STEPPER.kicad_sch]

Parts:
C401: 10 nF; C_0603_1608Metric
C402: 0.47uF; C_0603_1608Metric
C403, C406, C407: .1uF 100V; C_0805_2012Metric
C404: 47uF; CP_Elec_6.3x7.7
C405: 4.7uF 50V; C_0805_2012Metric
J401: Conn_01x04_MountingPin; JST_PH_B4B-PH-SM4-TB_1x04-1MP_P2.00mm_Vertical
R401: 1.5k; R_0603_1608Metric
R402, R403: 10k; R_0603_1608Metric
R404, R405: 0.1R; R_0805_2012Metric
RV401: 10k POT; Potentiometer_Bourns_TC33X_Vertical
TP401: TestPoint; TestPoint_THTPad_D1.0mm_Drill0.5mm
U401: DRV8825PWPR; HTSSOP-28-1EP_4.4x9.7mm_P0.65mm_EP3.4x9.5mm_ThermalVias

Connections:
+3V3: R401.2, R403.2; also elsewhere on the board
+VDC: C403.1, C404.1, C405.1, C406.2, C407.2, U401.4 (VMA), U401.11 (VMB); also elsewhere on the board
/PHI_STEPPER/3VP: C402.1, R402.2, RV401.3, U401.15 (V3P3OUT), U401.24 (MODE0), U401.25 (MODE1), U401.26 (MODE2)
GND: C402.2, C404.2, C405.2, C406.1, C407.1, J401.MP (MountPin), R404.1, R405.1, RV401.1, U401.14 (GND), U401.28 (GND), U401.29 (GND); also elsewhere on the board
unnamed: J401.1, U401.5 (AOUT1)
unnamed: J401.2, U401.7 (AOUT2)
unnamed: J401.3, U401.8 (BOUT2)
unnamed: J401.4, U401.10 (BOUT1)
unnamed: R401.1, U401.18 (!FAULT)
unnamed: R402.1, U401.27 (!HOME)
unnamed: R403.1, U401.17 (!SLEEP)
unnamed: RV401.2, TP401.1, U401.12 (AVREF), U401.13 (BVREF)
unnamed: C401.1, U401.1 (CP1)
unnamed: C401.2, U401.2 (CP2)
unnamed: R405.2, U401.6 (ISENA)
unnamed: R404.2, U401.9 (ISENB)
unnamed: C403.2, U401.3 (VCP)
PHI_DIR: U401.20 (DIR); also elsewhere on the board
PHI_ENABLE: U401.21 (!ENBL); also elsewhere on the board
PHI_RESET: U401.16 (!RESET); also elsewhere on the board
PHI_STEP: U401.22 (STEP); also elsewhere on the board

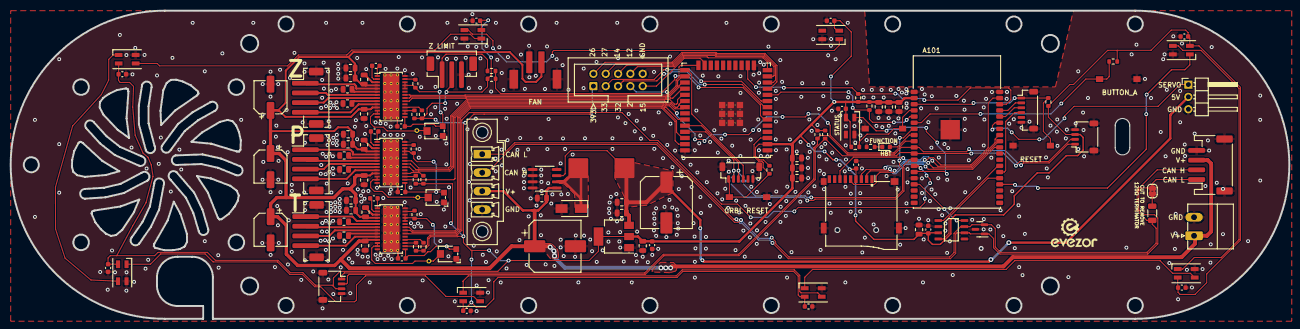
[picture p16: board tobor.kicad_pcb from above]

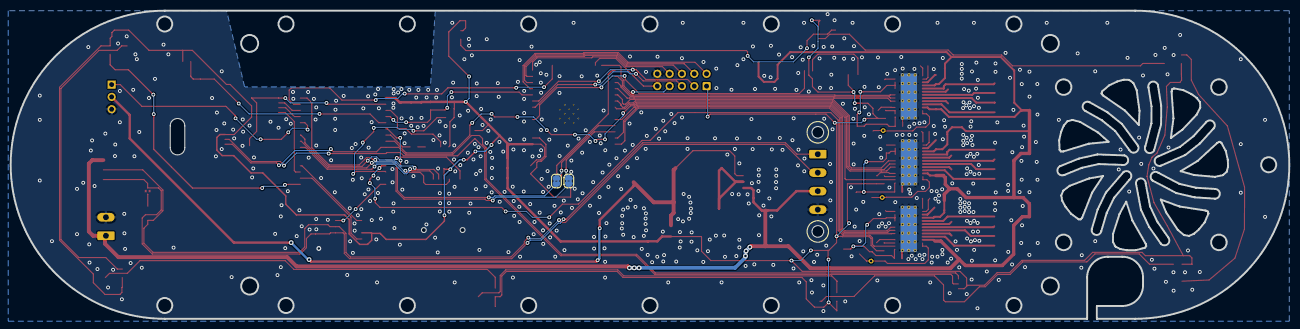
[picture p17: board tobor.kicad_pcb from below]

Board: 2 copper layers, 263.5 x 63.5 mm, 122 parts (2 on the bottom side), 106 nets.

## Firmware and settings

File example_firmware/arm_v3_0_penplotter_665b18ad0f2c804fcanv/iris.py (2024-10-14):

# import struct
try:
    import uasyncio as asyncio
# except (ModuleNotFoundError, ImportError): # TODO: make pyscript mpy have correct exceptions
except:
    import asyncio
import message
import nwk, os, collections, json, time
from floe import Bifrost
# from floe.network import base_parameters

class CanHeader:
    def __init__(self, *, 
                 adr: int, 
                 s: dict, 
                 header_bits: int=29, 
                 ad_bits: int=8, 
                 priority_bits: int=5, 
                #  fault_bits: int=8,  
                 packet_size=8, 
                 type_bits: int=5,
                 **k):
        """
        package [parameter priority bits: 5][address bits: 8][parameter bits: 11 ][type: 5 bits]
        parameter bits [pid][rr/rc/s/w]
        
        adr:0 -> EMCY
        adr:1 -> NETWORK
        adr:2 -> ZORG
        
        """
        self.s = s  # subscription list

        self.adr = adr  # this board's address
        self.header_bits = header_bits  # total # of bits
        self.ad_bits = ad_bits  # bits in address field
        self.num_adr = 2 ** ad_bits - 1
        self.priority_bits = priority_bits  # number of bits above address bits
        self.ad_mask = 2 ** self.ad_bits - 1
        self.type_bits = type_bits

        # constants for unpacking
        self.num_low = self.header_bits - self.ad_bits - self.priority_bits  # number of bits in low portion INCLUDES TYPE BITS
        self.low_mask = 2 ** self.num_low - 1  # also includes type bits
        self.high_mask = (2 ** self.priority_bits - 1) << (self.num_low + self.ad_bits)  # also includes type bits
        self.type_mask = 2 ** self.type_bits - 1
        
        self.packet_size = packet_size

        # constants for packing
        self.low_shft = self.num_low - self.type_bits
        self.pk_mask = 2 ** self.low_shft - 1

        # # network channel
        # self.fault = 2 ** fault_bits
        # self.nwk_l = int(2 ** header_bits / 2 ** ad_bits)
        # self.nwk_h = int(2 ** header_bits - self.nwk_l)
        # # print('channel width is ', self.nwk_l, ' h_nwk is ', self.nwk_h)
        # self.nwk_ad = 2 ** ad_bits - 1

    # ------------------------------------------------------------------------

    def unpack(self, h: int) -> tuple[int, int, int]:
        """
        unpack int header into type, address and pid
        return tuple(type, address, pid)
        """
        # print(h)
        low = h & self.low_mask
        high = h & self.high_mask
        # print('lh ', low, high)
        
        adr = h >> self.num_low & self.ad_mask
        if adr == self.num_adr:  # if adr high just move to adr low
            adr = 0
        return (
            adr,  # adr
            ((high >> self.ad_bits) + low) >> self.type_bits,  # pid
            h & self.type_mask,  # type
        )

    # ------------------------------------------------------------------------

    def pack(self, type: int, pid: int, adr: int) -> int:
        high = pid >> self.low_shft  # grab priority bits
        low = pid & self.pk_mask  # grab low bits
        hdr = ((((high << self.ad_bits) + adr) << self.low_shft) + low) << self.type_bits
        hdr |= type
        return hdr

class FakeBus():
    def __init__(self, iris):
        self.msg = iris.msg
        self.header = CanHeader(adr=3, s=iris.s)
    def subscribe(self, *a):
        pass
    def unsubscribe(self):
        pass
    def send(self, *a, **k):
        print(a, k)
    def rts(self):
        return True

Canvas = collections.namedtuple('Canvas', ['canvas_id','canvas_name'])


class Iris:
    def __init__(self):
        print('Iris initializing')
        self.id = ""
        # self.globals = {'iris': self} # the globals to be used by eval functions
        self.p = {}                 # Parameter Table with no adr
        self.s = {}                 # Subscription List {header: (pid, bundle)}

        self.n = {}                 # these are nwk and zorg functions, putting them here to keep p smaller
        
        # these are temporary until I figure out something better
        self.zorg = False
        self.locals = {'iris': self}  # namespace for repl, gene and eval functions
        
        self.ob = []                # Outbox
        self.obg = []               # Outbox generators
        
        self.webstuff = []          # Gui elements for web interface
        self.bifrost: Bifrost = Bifrost()
        
        self.core = None            # core element
        self.msg = message.Message(iris=self)
        
        self.bus = FakeBus(self)             # can bus pid
        self.buss = {}            # moving to multiple busses soon
        
        self.info = None
        try:
            self.ib = collections.deque((), 40, True)  # micopython with max len and overflow protection
        except TypeError:
            self.ib = collections.deque([])
        
        self.startup_events = 0  # are we awaiting startup events?
        
    def get_gui(self):
        
        def iter():
            for param in self.p.values():
                ws = param.gui()
                if ws:
                    yield json.dumps(ws)           
        def doit():
            yield "["
            yield ",".join(i for i in iter())
            yield "]"
        return "".join(doit())
    
    def on_startup(self, add_remove):
        if add_remove == 'add':
            self.startup_events += 1
        elif add_remove == 'remove':
            self.startup_events -= 1
            print('itss ', self.startup_events)
        else:
            pass
        
    async def wait_for_startup(self):
        while self.startup_events:
            await asyncio.sleep(.2)
            print('waiting on startup')
        return True
       
    def report(self):
        report = []
        report.append('**** Parameter Table ****')
        for pid, v in sorted(self.p.items()):
            _type = str(type(v)).replace("<class '", '').replace("'>", '')
            report.append(f'{pid}: {_type}')
        report.append('\n\n**** OUTBOX ****')
        for msg in self.ob:
            report.append(msg)
        # print('\n\n**** INTERNAL INBOX ****')
        # for msg in self.iib:
        #     print(msg)
        report.append('\n\n ********************** \n')
        return '\n'.join(report)
    
    def list_locals(self):
        return '\n'.join(f'{k}: {v}' for k,v in self.locals.items())
    
    def set_info(self, canvas_id, canvas_name):
        self.info = Canvas(canvas_id, canvas_name=canvas_name)
            
    def save(self):
        p = {}
        for pid, param in self.p.items():
            p[pid] = param.save()
        return p

    def send(self, *, pid, load, type=0, adr=None, is_generator=False) -> None:
        """ add to outbox """
        if adr is not None:
            # print('adr is not none', pid, adr, w)
            h = self.bus.header.pack(type=type, pid=pid, adr=adr)
        else:
            h = self.bus.header.pack(type=type, pid=pid, adr=self.bus.header.adr)
        # print('sending message: {} to outbox'.format(m))

        # put message in sorted order min lowest
        if is_generator:
            self.obg.append((h, load))
            return
        if len(self.ob) < 20:
            # TODO there is an overflow condition when bus is not working, fix this
            self.ob.append((h, load))

    async def cob(self):
        """ check outbox """
        while True:
            if self.ob:
                if self.bus.rts():
                    # print('sending message')
                    h, load = self.ob.pop(0)
                    self.bus.send(load, h)
            elif self.obg:  #outbox generators
                if self.bus.rts():
                    try:
                        load = next(self.obg[0][1])
                        h = self.obg[0][0]
                        self.bus.send(load, h)
                    except StopIteration:
                        print('done sending')
                        self.obg.pop(0)            
            await asyncio.sleep(.02)

    async def cib(self):
        """ check inbox """
        while True:
            if self.ib:
                msg_func, sub, load = self.ib.popleft()
                # print(msg_func, sub, load)
                msg_func(load, sub)
            await asyncio.sleep(0)

    def add_bus(self, label, bus):
        self.bus = bus
        
        self.buss[label] = bus

    def subscribe(self, header, pid, bundle):
        self.bus.subscribe(header, pid)  # busses like MQTT require subbing from broker
        if header in self.s:
            current_pid, bundle = self.s[header]
            if isinstance(pid, tuple):
                if pid in current_pid:
                    return
                subs = list(current_pid)
                subs.append(pid)
                subs = tuple(subs)
            else:
                if pid == current_pid:
                    return
                subs = (current_pid, pid)
            
            self.s[header] = (subs, bundle)
        else:
            self.s[header] = (pid, bundle)
    
    def unsubscribe(self, header):
        self.bus.unsubscribe(header)
        self.s.pop(header)

    def clear_subs(self):
        subs = list(self.s.keys())
        for sub in subs:
            print(f'unsubscribing: {sub}')
            self.bus.unsubscribe(sub)
            self.s.pop(sub)
    
    def add_hots(self, all_hots: dict[str, list[int]]):
        for pid, hots in all_hots.items():
            for hot in hots:
                self.p[int(hot)].add_hot(pid)

        
    def boot(self, start_mailboxes=False):
        pids = list(self.p.keys()) # p changes during iteration
        for pid in pids:
            self.p[pid].update()
        if start_mailboxes:
            loop = asyncio.get_event_loop()
            loop.create_task(self.cib())
            loop.create_task(self.cob())
        self.n.update(nwk.nwk)
        
        if self.core:
            self.core.boot()

        if 'on_startup' in self.locals:
            # this is a CodeBlock with name on_startup
            startup = self.locals.pop('on_startup')
            startup("None")  # event cannot be None 
                 
            



if __name__ == '__main__':
    print('iris test')
    # iris = Iris(adr=36, fault_bits=8, header_bits=29, ad_bits=10, priority_bits=3)
    # print(test := iris.msg.unpack(472186874))
    # print(iris.msg.pack(**test))

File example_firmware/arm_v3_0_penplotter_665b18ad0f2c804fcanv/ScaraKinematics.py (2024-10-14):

from Parameter import Parameter
from floe import make_var
import math, json
# from pprint import pprint
CartesianPosition = dict # this is a dict of a position
ScaraPosition = dict

class ScaraKinematics(Parameter):
    modals = ['move.linear', 'move.rapid']
    
    def __init__(self, theta_length:float, phi_length:float, max_segment_size: float, right_handed: bool, **k):
        super().__init__(**k)
        self.theta_len = theta_length
        self.phi_len = phi_length
        
        self.theta_2 = theta_length**2
        self.phi_2 = phi_length**2
        
        self.feed = 500
        self.right_handed = make_var(right_handed)
        
        
        self.work_offset = dict(x=0, y=0, z=0, a=0, b=0, c=0, rot=0)
        # self.work_offset.update(work_offset)
        # work_offset['rot'] = math.radians(work_offset['rot'])
        print(self.work_offset)

        self.max_seg = max_segment_size

        self.prev_scara: ScaraPosition = None
        self.prev_cart: CartesianPosition = dict(x=145, y=-250, z=0, a=0, b=0, c=0) 
    
    def gen(self, iterable):
        for line in iterable:
            if line:
                yield json.loads(line)
    
    def __call__(self, state):
        self.state = []
        g = self.gen(state.split('\n'))         
        for line in g:
            if line['cmd'] in self.modals:
                if 'x' in line or 'y' in line:
                    if line['cmd'] == 'move.linear':
                        line.pop('cmd')
                        for seg in self.segmentize(line):
                            self.state.append(seg)
                    else:  # line['cmd'] == 'move.rapid'
                        cart = line.copy()
                        cart.pop('cmd')
                        self.prev_cart.update(cart)
                        scara = self.ik(cart)
                        new_scara = {'cmd': 'move.rapid'}
                        new_scara.update(scara)
                        self.state.append(new_scara)
                        self.prev_scara = scara
                else:
                    self.state.append(line)
            else:
                self.state.append(line)
        
        
        self.state = '\n'.join(self.round(line) for line in self.state)
        self.send()
    
    @staticmethod 
    def round(line):
        for k, v in line.items():
            if isinstance(v, float):
                line[k] = round(v, 3)
        return json.dumps(line)
        
    def segmentize(self, end: CartesianPosition):
        """ 
        """
        if 'feed' in end:
            self.feed = end.pop('feed')
        if not self.prev_cart:
            # we are starting fresh and have no previous position
            # TODO: we must calculate this position manually
            start = dict(x=145, y=-257, z=0, a=0, b=0, c=0) 
            
        else:
            start = self.prev_cart
        
        # calculate the length of this line
        line_len = self.calc_dist(start, end)

        
        
        if line_len < self.max_seg:
            new_scara = {'cmd': 'move.linear'}
            cart = end.copy()
            scara = self.ik(cart)
            new_scara.update(scara)
            if self.prev_scara:
                try:
                    new_scara['feed'] = int(self.calc_dist(self.prev_scara, scara)/line_len * self.feed)   # feed is now a ratio of cart_dist/scara_dist
                except ZeroDivisionError:
                        new_scara['feed'] = 500    
            else:
                new_scara['feed'] = 500
            
            yield new_scara
            # print(new_scara)
            self.prev_scara = scara
            
            
        
        else:
            num_segs = int(math.ceil(line_len / self.max_seg))
            seg_len = line_len/num_segs
            for i in range(1, num_segs):
                new_scara = {'cmd': 'move.linear'}
                # interpolate
                cart = {axis: (i*end[axis]+(num_segs-i)*start[axis])/num_segs for axis in end.keys()}
                scara = self.ik(cart)
                new_scara.update(scara)
                if self.prev_scara:
                    try:
                        new_scara['feed'] = int(self.calc_dist(self.prev_scara, scara)/seg_len * self.feed) # feed is now a ratio of cart_dist/scara_dist
                    except ZeroDivisionError:
                        new_scara['feed'] = 500    
                else:
                    new_scara['feed'] = 500
                
                # print(new_scara) 
                self.prev_scara = scara
                yield new_scara
            
            new_scara = {'cmd': 'move.linear'}
            cart = end.copy()
            scara = self.ik(cart)
            new_scara.update(scara)
            new_scara['feed'] = self.calc_dist(self.prev_scara, scara)/seg_len * self.feed # feed is now a ratio of cart_dist/scara_dist
            self.prev_scara = scara
            
            yield new_scara
        
        self.prev_cart = end
        end['cmd'] = 'feed.linear'
    
    @staticmethod
    def calc_dist(start: dict, end: dict):
        if 'z' in end:
            return math.sqrt((end['x'] - start['x'])**2 + (end['y'] - start['y'])**2 + (end['z'] - start['z'])**2)
        return math.sqrt((end['x'] - start['x'])**2 + (end['y'] - start['y'])**2)
        
    def translate(self, pos: CartesianPosition):
        # rotate
        # print(f'f{pos = }')
        hyp = math.hypot(pos['x'], pos['y'])
        hyp_angle = math.atan2(pos['y'], pos['x'])
        new_hyp_angle = hyp_angle + self.work_offset['rot']
        
        pos['x'] = math.cos(new_hyp_angle) * hyp
        pos['y'] = math.sin(new_hyp_angle) * hyp

        # translate
        for axis, position in pos.items():
            pos[axis] = position + self.work_offset[axis]
            # print(f'{pos = }')
        return pos
    
    def fk(self, theta_deg, phi_deg, a_deg=None):
        theta = math.radians(theta_deg)
        phi = math.radians(phi_deg)
        c2 = (self.theta_2 + self.phi_2) - (2 * self.theta_len * self.phi_len * math.cos(math.pi-phi))
        c = math.sqrt(c2)
        B = math.acos((c2 + self.theta_2 - self.phi_2)/(2*c*self.theta_len))

        new_theta = theta + B
        # we implicitly to the coordinate tranform here
        y = -math.cos(new_theta)*c
        x = math.sin(new_theta)*c
        return x, y
    
    def ik(self, point: CartesianPosition) -> ScaraPosition:
        """ I like for 0,0 to be the arm facing straight down (-90 deg) for (theta:0, phi:0)

        Args:
            point (CartesianPosition): _description_
            right_handed (bool, optional): _description_. Defaults to True.
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
